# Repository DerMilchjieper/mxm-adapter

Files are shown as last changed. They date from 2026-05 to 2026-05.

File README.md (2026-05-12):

# mxm-adapter

Research and staged hardware concept for reusing the HP ZBook 17 G5 MXM dGPU connector as an external PCIe/OCuLink host link.

## Current design decision

**RevA targets MXM -> OCuLink x4, not MXM -> external PCIe x16.**

Reasoning:

- x4 keeps the first prototype small enough to route and debug.
- OCuLink provides a mechanically realistic cable exit from a laptop chassis.
- Existing OCuLink eGPU docks can supply the PCIe x16 slot and GPU power externally.
- A passive MXM -> external x16 riser has significantly higher signal-integrity and mechanical risk.
- Dual external GPUs are out of scope for RevA and require either host bifurcation that HP has not documented or an active PCIe switch.

## Safety boundary

Do **not** power a desktop PCIe slot or desktop GPU from the notebook MXM rails. The external GPU dock/backplane must have its own ATX/SFX/server PSU. The notebook-side board should only carry PCIe, clock, reset, presence/sideband signals, and protected low-power logic where required.

## Repository layout

```text
.
├── docs/
│   ├── architecture.md
│   ├── assumptions.md
│   ├── dual-gpu-feasibility.md
│   ├── risk-register.md
│   └── validation-plan.md
├── hardware/
│   └── revA-mxm-to-oculink-x4/
│       ├── block-diagram.md
│       ├── netmap.csv
│       ├── schematic-concept.md
│       ├── stackup-and-layout-rules.md
│       └── bom-categories.md
└── README.md
```

## RevA milestone goals

1. Build a passive/mostly-passive MXM Type-B host-side interposer concept.
2. Route PCIe lanes 0-3, REFCLK, PERST#, CLKREQ#, WAKE#, SMBus, PRSNT and selected power-state signals to an OCuLink 4i connector.
3. Keep GPU slot power fully outside the laptop.
4. Validate boot behavior, PCIe enumeration, link width and link speed before attempting x8/x16.

## Non-goals for RevA

- No hotplug support.
- No desktop PCIe slot inside the notebook.
- No x8/x16 cable riser.
- No dual-GPU switch board.
- No attempt to spoof a full HP MXM GPU module unless measurements prove HP EC/BIOS requires it.

## Status

Concept-only. Not fabrication-ready. HP-specific MXM socket behavior must be measured on the actual ZBook 17 G5 before PCB release.

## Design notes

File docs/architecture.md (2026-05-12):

# Architecture

## Recommended architecture: MXM to OCuLink x4

```mermaid
flowchart LR
    CPU[CPU PEG / MXM host interface] --> MXM[MXM 3.0 Type-B edge fingers]
    MXM --> INT[Notebook-side interposer PCB]
    INT --> OC[OCuLink 4i connector]
    OC --> CABLE[External OCuLink cable]
    CABLE --> DOCK[Powered OCuLink eGPU dock]
    DOCK --> GPU[Desktop GPU]
    PSU[ATX/SFX PSU] --> DOCK
    PSU --> GPU
```

## Why x4 OCuLink first

The MXM slot can theoretically expose up to 16 PCIe lanes, but a first prototype should not try to export all lanes. PCIe Gen3 x16 over a custom laptop-exit cable has high signal-integrity risk. A 4-lane OCuLink path is materially easier to validate and uses existing cable/dock ecosystems.

## Alternative: MXM to PCIe x16 external riser

```mermaid
flowchart LR
    MXM[MXM host connector] --> PCB[Interposer / translator PCB]
    PCB --> Riser[High-speed x16 cable/riser]
    Riser --> Slot[External PCIe x16 slot backplane]
    ATX[ATX/SFX PSU] --> Slot
    ATX --> AUX[GPU 6/8-pin or 12VHPWR]
    Slot --> GPU[Desktop GPU]
```

This is theoretically possible but not recommended for RevA. It requires a custom external backplane, high-quality cable assembly, careful power sequencing, and likely redrivers/retimers for robustness.

## Minimal signal groups

### PCIe high speed

- PETp/n[0..3] from host to device
- PERp/n[0..3] from device to host
- REFCLKp/n

### PCIe control / sideband

- PERST#
- CLKREQ#
- WAKE#
- PRSNT#/detect strap equivalents
- SMBus SCL/SDA, isolated or strap-selectable

### Power / reference

- GND stitching and shield grounding
- 3.3 V sense / low-power pull-up domain only if required
- No GPU slot 12 V drawn from MXM

## Power architecture

The external dock/backplane must provide:

- PCIe slot 12 V
- PCIe slot 3.3 V
- AUX 6/8-pin or 12VHPWR GPU power
- over-current protection
- controlled power-on sequencing

The notebook-side board should avoid taking meaningful power from the MXM slot. Any logic rail should be current-limited and fuse-protected.

## Expected user workflow

1. Power off notebook.
2. Connect OCuLink cable.
3. Power external dock/PSU first.
4. Boot notebook.
5. Check PCIe enumeration.
6. Install GPU driver only after stable enumeration.

Hotplug is explicitly not supported for RevA.

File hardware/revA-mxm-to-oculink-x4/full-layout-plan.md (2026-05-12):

# Full RevA layout plan

## Objective

Create a measurement-first MXM Type-B to OCuLink x4 interposer that can be mechanically tested in the HP ZBook 17 G5 and electrically validated against a powered external OCuLink eGPU dock.

## Board concept

- Approximate board class: MXM-B-sized interposer / edge-card surrogate.
- Provisional outline: 94 mm x 32 mm.
- Edge: MXM placeholder at notebook socket side.
- Cable: OCuLink 4i connector near outer edge/cable-exit side.
- Debug: sideband strap matrix and test pads placed away from high-speed corridor.

## Functional blocks

### J1: MXM Type-B host edge

Purpose:

- Mate with the ZBook MXM socket.
- Pick off PCIe lane group 0-3, REFCLK and sideband pins.

Status:

- Placeholder only.
- Requires verified edge-card geometry and HP-specific pin map.

### J2: OCuLink 4i connector

Purpose:

- Export four PCIe lanes to a powered eGPU dock.

Status:

- Placeholder only.
- Replace with exact vendor part footprint before PCB release.

### JP1: sideband strap matrix

Purpose:

- Allow controlled population of PERST#, CLKREQ#, WAKE#, SMBus, PRSNT/detect and possible EC straps.

Default population:

- PERST#: 0R pass-through after verification.
- CLKREQ#: DNI initially; populate if needed.
- WAKE#: DNI initially; populate if needed.
- SMBus: DNI/isolate by default.
- PRSNT/detect: DNI until measured.

### TPx: debug pads

Purpose:

- Probe PERST#, CLKREQ#, WAKE#, SMBus, PRSNT and low-power rails.

Rule:

- No test pads on high-speed PCIe pairs in RevA.

## Routing strategy

1. Lock mechanical outline and connector positions first.
2. Route PCIe lane 0-3 pairs from MXM to OCuLink with the shortest possible path.
3. Route REFCLK as a differential clock pair with continuous reference plane.
4. Add ground stitching around connector transitions.
5. Route sideband signals around the high-speed corridor.
6. Add no high-speed stubs, no unnecessary vias and no high-speed test pads.
7. Add silkscreen warnings and revision labels.

## Suggested layer usage

### 6-layer RevA

| Layer | Use |
|---|---|
| L1 | PCIe/REFCLK primary routing |
| L2 | solid GND reference |
| L3 | sideband / low-speed |
| L4 | low-power islands / sideband |
| L5 | solid GND reference |
| L6 | optional high-speed escape / sideband |

## Differential-pair rules

- PCIe data: target 85 ohm differential.
- REFCLK: target per connector/vendor guidance, commonly 100 ohm differential.
- Final width/gap must come from fabricator stackup calculator, not the placeholder KiCad values.
- Match P/N within each pair.
- Keep inter-pair spacing generous.
- Avoid plane splits.
- Avoid via stubs.

## Placement constraints

### MXM edge

- No tall components near insertion edge.
- No copper/parts in mechanical keepout regions until socket geometry is verified.
- Edge bevel/plating must be manufacturer-reviewed.

### OCuLink connector

- Place near cable exit.
- Add mechanical strain relief to chassis or bracket, not the motherboard.
- Do not let cable insertion force lever against MXM socket.

### Strap/debug area

- Place on accessible top side if the bottom cover is removed.
- Keep away from high-speed channel.
- Label all straps clearly.

## Proposed schematic sheets

1. `J1_MXM_Host`: MXM connector, HP pin verification notes.
2. `PCIE_x4_Path`: lane 0-3 and REFCLK pass-through.
3. `J2_OCuLink`: OCuLink connector and shell/shield strategy.
4. `Sideband_Straps`: PERST, CLKREQ, WAKE, SMBus, PRSNT, optional thermal.
5. `Debug_Protection`: low-power fuse, test pads, ESD footprints DNI.
6. `Mechanical`: mounting/keepout notes and fabrication warnings.

## Fabrication gate

Do not generate Gerbers until all of the following are true:

- MXM pin mapping verified.
- MXM edge geometry verified with coupon.
- OCuLink footprint replaced with real vendor drawing.
- Stackup impedance solved with fabricator.
- DRC passes.
- SI review completed.
- Power isolation reviewed.
- ZBook boot behavior with missing MXM module understood.

## RevA population variants

### Variant A: passive-minimal

- J1, J2 populated.
- PERST# pass-through only after verified.
- All SMBus/detect/thermal straps DNI.

### Variant B: measured-detect

- Same as A.
- PRSNT/detect straps populated to match measured original HP MXM module behavior.

### Variant C: EC-compatible

- Same as B.
- Optional thermal/EC spoof components populated if HP EC requires them.

## Why no x16 in this layout

A full x16 riser from MXM would require a different connector/cable/backplane strategy, likely redrivers/retimers, and far more severe signal-integrity review. It also increases mechanical risk inside the laptop. RevA x4 is the safe proof-of-concept path.

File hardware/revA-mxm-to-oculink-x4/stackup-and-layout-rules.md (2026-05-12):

# Stackup and layout rules

## Recommended PCB stackup

Minimum: 6 layers. Preferred: 8 layers if board area and escape routing are tight.

### 6-layer candidate

1. L1: high-speed signals / short escapes
2. L2: solid GND reference
3. L3: low-speed signals / sideband
4. L4: power islands / sideband
5. L5: solid GND reference
6. L6: high-speed signals / connector escape

### 8-layer candidate

1. L1: high-speed signals
2. L2: solid GND
3. L3: high-speed signals if needed
4. L4: solid GND
5. L5: low-speed / power islands
6. L6: solid GND
7. L7: sideband
8. L8: mechanical/debug/low-speed

## Impedance targets

- PCIe data pairs: 85 ohm differential target.
- REFCLK: follow connector/cable vendor guidance; commonly routed as 100 ohm differential clock.
- Use the PCB fabricator's field solver for the chosen stackup.

## Routing constraints

- Keep MXM-to-OCuLink high-speed path as short as mechanically possible.
- Avoid layer changes for PCIe pairs where possible.
- If vias are required, use symmetric via transitions and minimize stubs.
- Maintain continuous GND reference under every high-speed pair.
- Do not cross plane splits.
- Avoid test pads, stubs and probing structures on high-speed pairs.
- Do not place ESD devices on high-speed nets unless their capacitance and placement are validated.
- Keep pair-to-pair spacing wide enough to control crosstalk.
- Length match P/N within each pair according to fabricator/SI guidance.
- Inter-lane matching is less critical than intra-pair matching for PCIe but should still be sane.

## OCuLink connector area

- Follow the chosen connector vendor's footprint exactly.
- Provide shell/shield grounding pads and stitching vias.
- Add mechanical reinforcement if the cable exits the chassis with stress.
- Define whether shield bonds directly to digital GND or via RC/ESD structure after mechanical/chassis review.

## MXM edge area

- Edge fingers require correct thickness, bevel and plating.
- Confirm insertion depth and keeper/retention behavior in the ZBook MXM socket.
- Verify no components collide with heatsink, frame, keyboard deck, fan duct or bottom cover.

## Redriver/retimer decision

RevA starts passive. Add redriver/retimer only after:

1. Passive x4 fails to train reliably at Gen3.
2. Gen2 works but Gen3 is unstable.
3. Cable length cannot be reduced.
4. Eye/SI evidence suggests insertion loss is the dominant issue.

A retimer spin is a different architecture and should become RevB.

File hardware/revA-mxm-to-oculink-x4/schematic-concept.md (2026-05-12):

# RevA schematic concept

## Sheet 1: MXM host connector

Components:

- J1: MXM 3.0 Type-B edge-finger symbol/footprint placeholder.
- TP group: all sideband pins broken out.
- DNI strap resistors for presence/detect and EC-facing signals.

Notes:

- Use a mechanically accurate MXM Type-B outline before PCB work.
- Pin numbering must be verified against the chosen connector/edge-footprint convention.
- Do not trust generic internet pinouts for HP-specific behavior.

## Sheet 2: PCIe x4 high-speed path

Nets:

- PET/PER lanes 0-3.
- REFCLK pair.
- Optional AC-coupling capacitor footprints only where required by the interface convention. Do not blindly duplicate endpoint-side coupling if the dock/card already provides it.

Components:

- J2: OCuLink 4i connector.
- Optional low-cap ESD arrays, DNI by default until SI budget is reviewed.
- Optional common-mode choke footprints are not recommended for first spin unless justified by the connector/cable vendor.

Routing:

- No vias if possible between MXM breakout and OCuLink connector.
- If vias are unavoidable, use backdrill-capable stackup or keep stubs minimal.
- Length-match within each differential pair first; inter-lane matching is secondary for PCIe.

## Sheet 3: sideband and strap matrix

Signals:

- PERST#
- CLKREQ#
- WAKE#
- PRSNT#/detect
- SMBus SCL/SDA
- optional THERM#/ALERT#/FAN_TACH-like signals if HP exposes them on MXM

Implementation:

- 0-ohm jumpers for direct pass-through vs isolation.
- Pull-up/down resistor footprints for detect straps.
- Series resistor placeholders on sideband lines.
- Test pads before and after jumpers.

Default population:

- PERST#: pass-through populated.
- PRSNT#/detect: unpopulated until measured.
- SMBus: isolated by default.
- CLKREQ#/WAKE#: testable; populate as required.
- Thermal spoof: DNI.

## Sheet 4: protected low-power domain

Goal:

Only provide local pull-ups or indicators if required. Do not create a significant load on the MXM power rails.

Possible components:

- Resettable fuse or eFuse for any 3.3 V use.
- TVS/ESD for exposed sideband connector pins.
- Power-good LED, DNI by default.

## Sheet 5: mechanical and debug

- Mounting holes matching safe internal locations only after ZBook mechanical survey.
- Strain relief for OCuLink cable.
- Ground test pads.
- Optional board ID EEPROM footprint, DNI.

## Explicitly excluded from RevA

- PCIe switch.
- Redriver/retimer.
- x8/x16 export.
- ATX power controller.
- External PCIe slot.
- Any attempt to source GPU slot power from the notebook.

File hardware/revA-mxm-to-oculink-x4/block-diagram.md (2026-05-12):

# RevA block diagram: MXM to OCuLink x4

```mermaid
flowchart TB
    subgraph Notebook[HP ZBook 17 G5]
        CPU[CPU PEG root port]
        EC[Embedded controller / BIOS]
        MXM[MXM Type-B host connector]
        CPU --> MXM
        EC -. detect / reset / thermal / SMBus .- MXM
    end

    subgraph Interposer[RevA MXM-to-OCuLink interposer]
        EDGE[MXM edge connector fingers]
        STRAPS[strap matrix + DNI options]
        TP[test pads]
        ESD[low-cap ESD footprints, DNI unless validated]
        OCULINK[OCuLink 4i SFF-8612/SFF-8611]
        EDGE --> STRAPS
        EDGE --> TP
        EDGE --> ESD
        ESD --> OCULINK
    end

    subgraph External[eGPU side]
        CABLE[OCuLink cable]
        DOCK[Powered OCuLink eGPU dock]
        GPU[Desktop GPU]
        PSU[ATX/SFX/server PSU]
        PSU --> DOCK
        PSU --> GPU
        DOCK --> GPU
    end

    MXM --> EDGE
    OCULINK --> CABLE
    CABLE --> DOCK
```

## Board partitions

1. **MXM finger area**: mates with the notebook MXM socket and keeps all high-speed breakout lengths short.
2. **High-speed escape region**: routes PCIe x4 and REFCLK with uninterrupted reference planes.
3. **Sideband strap/test region**: exposes PERST#, CLKREQ#, WAKE#, PRSNT#/detect, SMBus, optional thermal spoof.
4. **Cable connector region**: OCuLink 4i with robust retention and mechanical strain relief.

## Intended mechanical shape

The board should mimic the MXM module insertion edge and occupy the minimum internal volume required to exit an OCuLink cable path. A flex or short cabled OCuLink pigtail may be mechanically easier than a rigid connector placed directly at the MXM area, but this must not violate PCIe Gen3 signal-integrity limits.

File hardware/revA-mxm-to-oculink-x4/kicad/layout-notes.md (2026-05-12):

# KiCad layout skeleton

This directory contains a **real KiCad project skeleton** for the RevA MXM-to-OCuLink-x4 concept.

## Files

- `revA-mxm-to-oculink-x4.kicad_pro` — KiCad project settings and placeholder net classes.
- `revA-mxm-to-oculink-x4.kicad_sch` — schematic stub pointing to the documentation-first design.
- `revA-mxm-to-oculink-x4.kicad_pcb` — mechanical/electrical PCB skeleton.

## What is in the PCB file

- 94 mm × 32 mm provisional board outline.
- MXM Type-B edge-finger **placeholder** with 314 pads.
- OCuLink 4i connector **placeholder**.
- Sideband strap-matrix placeholder.
- Preliminary PCIe x4 / REFCLK / sideband net names.
- Drawing-layer high-speed corridor and “do not fabricate” markings.

## What is intentionally not solved yet

- Exact HP ZBook 17 G5 MXM pin mapping.
- Verified MXM edge-card geometry, bevel, plating and insertion depth.
- Verified OCuLink connector footprint from a real vendor part.
- Verified controlled-impedance stackup from a board fabricator.
- Exact lane mapping, polarity, AC-coupling locations and sideband strap values.
- Mechanical retention and cable strain-relief.

## Why the layout is not fabrication-ready

This file is meant to be opened in KiCad to start mechanical review and layout planning. It is **not** a Gerber-ready adapter. The placeholder pad assignments include `_TBD` in net names on purpose. Do not remove that until the ZBook MXM slot has been measured and reviewed.

## Next layout actions

1. Replace the MXM placeholder with a verified edge-card geometry.
2. Replace the OCuLink placeholder with the exact connector vendor footprint.
3. Update `netmap.csv` with measured HP-specific MXM pin mapping.
4. Re-annotate nets in schematic and PCB.
5. Define final 6- or 8-layer stackup with the PCB manufacturer.
6. Run DRC, SI review and mechanical clearance review.
7. Build a non-electrical mechanical coupon before any powered PCB.

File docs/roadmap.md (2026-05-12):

# Roadmap

## Stage 0: baseline OCuLink eGPU

Goal: prove the laptop can use an external GPU through an easier path.

- Use M.2 NVMe -> OCuLink adapter.
- Use powered OCuLink dock.
- Connect monitor directly to GPU.
- Record link speed, link width, boot behavior and driver stability.

Exit criteria:

- Stable boot and gaming/compute workload on M.2 OCuLink.

## Stage 1: MXM platform characterization

Goal: learn how HP handles the MXM slot.

- Document installed MXM module.
- Test boot with MXM module removed if safe.
- Record BIOS behavior.
- Measure sideband timing.
- Identify detect/thermal dependencies.

Exit criteria:

- Known boot behavior with and without MXM module.
- Candidate sideband requirements identified.

## Stage 2: mechanical coupon

Goal: validate board fit without electrical risk.

- Fabricate edge-card outline coupon.
- Validate thickness, bevel, insertion depth and retention.
- Validate OCuLink cable path.
- Validate no chassis/heatsink collision.

Exit criteria:

- Physical fit confirmed.
- Cable strain-relief concept confirmed.

## Stage 3: RevA passive x4 board

Goal: enumerate one external GPU over MXM-derived PCIe x4.

- Route lanes 0-3 to OCuLink.
- Add sideband straps/test pads.
- Keep SMBus isolated by default.
- Use external powered OCuLink dock.

Exit criteria:

- External GPU enumerates.
- Stable Gen2 x4 minimum; Gen3 x4 target.

## Stage 4: RevB robustness spin

Only if RevA proves the platform concept.

Potential additions:

- Redriver/retimer.
- Improved mechanical strain relief.
- Better sideband conditioning.
- Optional x8 if mechanical/SI budget supports it.

## Stage 5: dual-GPU experiment

Only after M.2 OCuLink and MXM OCuLink are independently stable.

- Boot with both external paths populated.
- Record PCIe topology.
- Test AMD gaming GPU + Nvidia compute GPU split.
- Avoid multi-GPU gaming as a target.

## Stage 6: x16 riser exploration

This remains a research branch, not the default product path.

Requirements before attempting:

- Proven MXM enumeration.
- High-speed layout review.
- External PCIe slot power/backplane design.
- Mechanical enclosure concept.
- Acceptance that redriver/retimer may be required.

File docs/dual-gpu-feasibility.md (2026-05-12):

# Dual external GPU feasibility

## Question

Can the ZBook 17 G5 theoretically run two external desktop GPUs, for example:

1. GPU A through M.2 NVMe -> OCuLink x4.
2. GPU B through MXM -> OCuLink x4 or MXM -> PCIe riser.

## Short answer

**Theoretically yes, practically uncertain and not a RevA goal.**

The platform may expose independent PCIe root ports for the CPU PEG/MXM path and PCH/M.2 NVMe path. If firmware enumerates both, Windows/Linux can generally handle multiple GPUs. The hard blockers are firmware behavior, physical integration, power sequencing and driver stability.

## Likely topology

```mermaid
flowchart TB
    CPU[i7-8850H CPU]
    PCH[Mobile PCH]
    MXM[MXM dGPU slot]
    M2[M.2 NVMe slot]
    OC1[OCuLink dock A]
    OC2[OCuLink dock B]
    GPU1[External GPU 1]
    GPU2[External GPU 2]

    CPU -->|PEG lanes, originally dGPU| MXM
    CPU -->|DMI link| PCH
    PCH -->|PCIe x4 NVMe root port| M2
    MXM --> OC1 --> GPU1
    M2 --> OC2 --> GPU2
```

## Bandwidth considerations

- MXM-derived GPU path could be CPU PEG and avoid PCH/DMI bottleneck if firmware exposes it cleanly.
- M.2 NVMe-derived OCuLink path likely traverses the PCH and DMI link.
- Two GPUs doing heavy peer-to-peer or simultaneous host transfers can contend for CPU, memory, DMI and thermal/power management.
- For gaming on one GPU and compute on the other, bandwidth contention may be acceptable.
- For two gaming GPUs, modern multi-GPU rendering is mostly unsupported and not worthwhile.

## Firmware constraints

Potential blockers:

- BIOS may require an HP-recognized MXM module.
- BIOS may not initialize external GPU-like endpoint on MXM without video BIOS expectations.
- BIOS may not support bifurcation of MXM PEG lanes into multiple devices.
- M.2 port may not support hotplug and must see device at boot.
- Boot graphics selection may conflict with external-only paths.

## Driver constraints

- AMD + Nvidia mixed drivers are usually possible but can be messy.
- Nvidia CMP cards may be compute-only/no-display and better suited to CUDA workloads.
- AMD eGPU for display plus Nvidia CMP for compute is an attractive theoretical split.
- Anti-cheat and VM passthrough scenarios can add unrelated failure modes.

## Power and mechanical constraints

Two external GPUs require:

- two powered docks or a custom dual-slot external backplane;
- independent PSU capacity;
- safe power sequencing;
- mechanically safe cable exits;
- no load on notebook internal GPU power rails.

## Practical recommendation

1. First validate M.2 -> OCuLink with one GPU.
2. Then validate MXM -> OCuLink x4 as RevA.
3. Only after both are independently stable, attempt simultaneous enumeration.
4. Do not design a dual-GPU board until single-link MXM behavior is proven.

## Best theoretical use case

- External AMD/Nvidia gaming GPU on one link, monitor attached directly.
- One or more Nvidia CMP/compute GPUs in a separate desktop/server or on another dock for CUDA/ComfyUI/Ollama experiments.

## Worst use case

- Two external gaming GPUs for combined rendering. This is not a sensible target because modern games rarely support explicit multi-GPU effectively.

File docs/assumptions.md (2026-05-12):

# Design assumptions

## Target platform

- Host notebook: HP ZBook 17 G5 mobile workstation.
- CPU family: Intel 8th Gen H-series, user-reported i7-8850H.
- Internal dGPU slot: MXM 3.0 Type B class connector/module form factor.
- Existing external path: M.2 NVMe to OCuLink is treated as the lower-risk baseline.

## Known unknowns

The following must be verified by measurement or official board-level documentation before any PCB is fabricated:

1. Exact HP MXM pin usage and any vendor-specific straps.
2. Whether the ZBook firmware enumerates a non-GPU PCIe endpoint on the MXM link.
3. Required PRSNT#/module-detect behavior.
4. Required thermal/fan/EC signals when no HP MXM module is present.
5. Whether PEG lanes are x16-only or can train down to x8/x4 without a valid MXM vBIOS device.
6. Whether the system boots without an installed MXM graphics module.
7. Whether internal display routing depends on the removed MXM dGPU.

## Conservative electrical assumptions

- Use PCIe Gen3 as the design target.
- Assume 85 ohm differential impedance for PCIe data pairs.
- Assume 100 ohm differential impedance for REFCLK unless connector/cable vendor specifies otherwise.
- Treat all high-speed lanes as polarity-sensitive until verified.
- Avoid passive cable lengths beyond validated OCuLink cable assemblies.
- Do not route desktop slot power through the notebook-side PCB.

## Firmware assumptions

The HP BIOS/EC may require MXM presence and thermal-management signals even if the external GPU is electrically valid. RevA must therefore expose test pads and strap options for:

- PRSNT#/module detect
- SMBus pull-ups/isolation
- WAKE#
- CLKREQ#
- PERST# observation/injection
- optional thermal sensor spoofing footprint, DNI by default

## Design philosophy

RevA is a measurement-first board. It should make the platform observable before it tries to maximize performance.

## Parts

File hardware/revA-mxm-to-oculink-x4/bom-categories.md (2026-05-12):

# BOM categories

## Connector and mechanical

- MXM Type-B edge-card PCB implementation or mating connector strategy, depending on final mechanical approach.
- OCuLink 4i connector, SFF-8612/SFF-8611 family depending on cable/dock.
- Cable-retention bracket or strain-relief hardware.
- Kapton/insulation films for internal chassis clearance.
- Mounting hardware only where it does not stress the ZBook motherboard.

## Passive high-speed path

- AC-coupling capacitor footprints if required by the chosen topology.
- Optional 0-ohm lane-swap/polarity rework footprints only if they do not create stubs.
- Low-cap ESD arrays, DNI by default.

## Sideband and straps

- 0-ohm jumpers for PERST#, CLKREQ#, WAKE#, SMBus, detect lines.
- Pull-up/pull-down resistor arrays for presence and EC straps.
- Series resistors for sideband damping/isolation.
- Test pads for every sideband net.

## Protection and low-power

- Resettable fuse/eFuse for any local 3.3 V usage.
- TVS for low-speed external-facing nets if exposed.
- Optional LED indicators, DNI by default.

## Debug

- Ground test loops.
- PERST#/CLKREQ#/WAKE# test pads.
- SMBus test pads.
- Optional tiny logic-analyzer header if it fits mechanically.

## External dock requirements

The external dock is treated as a separate assembly and must provide:

- PCIe slot connector.
- ATX/SFX/server PSU input.
- PCIe slot 12 V and 3.3 V.
- AUX GPU power cabling.
- Power switch and power-good behavior.
- Physical GPU support.

RevA should be compatible with an existing powered OCuLink eGPU dock instead of implementing this from scratch.

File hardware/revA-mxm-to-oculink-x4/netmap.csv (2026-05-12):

net_name | source_group | destination_group | required_for_reva | notes
PCIE_TX0_P | MXM PET lane 0 + | OCuLink host TX lane 0 + | yes | Verify MXM lane orientation against HP board and OCuLink pinout
PCIE_TX0_N | MXM PET lane 0 - | OCuLink host TX lane 0 - | yes | Pair length match tightly
PCIE_RX0_P | MXM PER lane 0 + | OCuLink host RX lane 0 + | yes | Verify polarity and lane reversal support
PCIE_RX0_N | MXM PER lane 0 - | OCuLink host RX lane 0 - | yes | Pair length match tightly
PCIE_TX1_P | MXM PET lane 1 + | OCuLink host TX lane 1 + | yes | Verify MXM lane orientation against HP board and OCuLink pinout
PCIE_TX1_N | MXM PET lane 1 - | OCuLink host TX lane 1 - | yes | Pair length match tightly
PCIE_RX1_P | MXM PER lane 1 + | OCuLink host RX lane 1 + | yes | Verify polarity and lane reversal support
PCIE_RX1_N | MXM PER lane 1 - | OCuLink host RX lane 1 - | yes | Pair length match tightly
PCIE_TX2_P | MXM PET lane 2 + | OCuLink host TX lane 2 + | yes | Verify MXM lane orientation against HP board and OCuLink pinout
PCIE_TX2_N | MXM PET lane 2 - | OCuLink host TX lane 2 - | yes | Pair length match tightly
PCIE_RX2_P | MXM PER lane 2 + | OCuLink host RX lane 2 + | yes | Verify polarity and lane reversal support
PCIE_RX2_N | MXM PER lane 2 - | OCuLink host RX lane 2 - | yes | Pair length match tightly
PCIE_TX3_P | MXM PET lane 3 + | OCuLink host TX lane 3 + | yes | Verify MXM lane orientation against HP board and OCuLink pinout
PCIE_TX3_N | MXM PET lane 3 - | OCuLink host TX lane 3 - | yes | Pair length match tightly
PCIE_RX3_P | MXM PER lane 3 + | OCuLink host RX lane 3 + | yes | Verify polarity and lane reversal support
PCIE_RX3_N | MXM PER lane 3 - | OCuLink host RX lane 3 - | yes | Pair length match tightly
REFCLK_P | MXM PCIe reference clock + | OCuLink REFCLK + | yes | Route as clock differential pair; consider AC-coupling only if spec requires
REFCLK_N | MXM PCIe reference clock - | OCuLink REFCLK - | yes | Route as clock differential pair
PERST_N | MXM reset sideband | OCuLink PERST# | yes | Expose test pad and optional buffer/level option
CLKREQ_N | MXM clock request sideband | OCuLink CLKREQ# | maybe | Strap/test; required if platform uses L1 substates or dynamic clocking
WAKE_N | MXM wake sideband | OCuLink WAKE# | maybe | Expose test pad; may be optional for always-on external dock
SMB_CLK | MXM SMBus clock | OCuLink/dock SMBus or isolated pad | maybe | Default DNI isolation; avoid bus conflict until measured
SMB_DATA | MXM SMBus data | OCuLink/dock SMBus or isolated pad | maybe | Default DNI isolation; avoid bus conflict until measured
PRSNT_DETECT | MXM module present strap | strap matrix | yes | Populate only after HP detect behavior is measured
THERM_ALERT | MXM thermal/alert if present | strap/test/optional spoof | unknown | Do not assume; verify HP EC requirements
3V3_AUX_SENSE | MXM low power rail/test | logic pull-ups only | no | Current-limit if used; do not power external dock
GND | MXM ground | OCuLink shield and signal reference | yes | Use dense stitching | connector shell strategy to be reviewed
SHIELD | OCuLink connector shell | chassis/cable shield | yes | Define chassis vs digital ground bond after mechanical review
RESERVED_X8_LANES | MXM lanes 4-7 | not connected in RevA | no | Escape/test pads optional only
RESERVED_X16_LANES | MXM lanes 8-15 | not connected in RevA | no | Do not route on RevA unless board area allows measurement pads

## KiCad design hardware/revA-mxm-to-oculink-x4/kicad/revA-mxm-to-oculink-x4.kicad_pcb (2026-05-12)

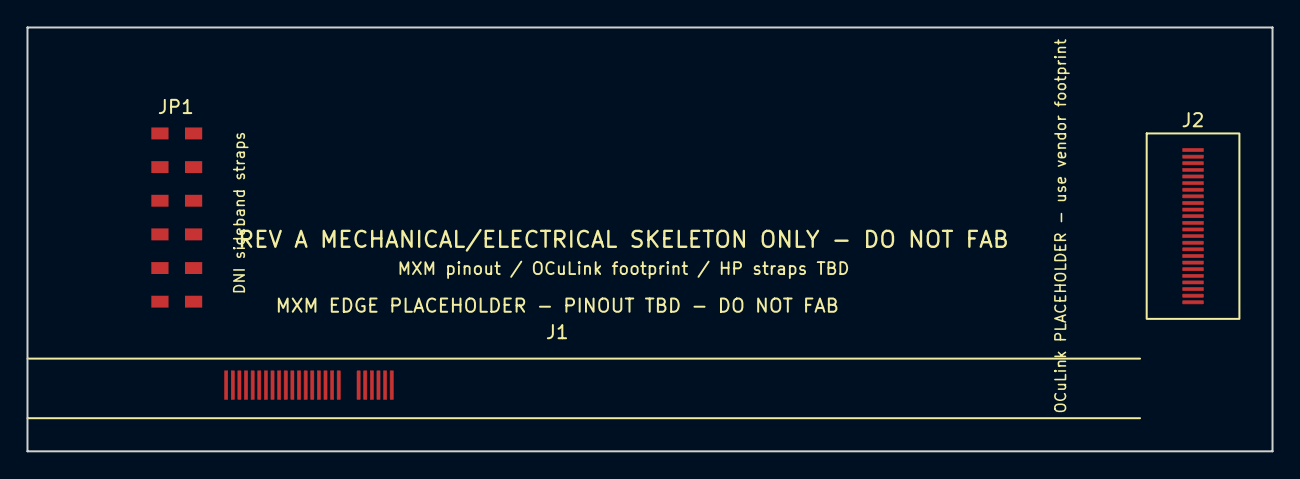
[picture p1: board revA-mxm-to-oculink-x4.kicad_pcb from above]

Board: 6 copper layers, 94.0 x 32.0 mm, 3 parts (0 on the bottom side), 24 nets, no tracks yet.

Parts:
J1: MXM3_TYPE_B_EDGE_PLACEHOLDER; MXM3_TYPE_B_EDGE_PLACEHOLDER_DO_NOT_FAB
J2: OCuLink_4i_PLACEHOLDER; OCULINK_4I_PLACEHOLDER_DO_NOT_FAB
JP1: DNI_STRAPS; SIDEBAND_STRAP_MATRIX_0603_PLACEHOLDER

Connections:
CLKREQ_N_TBD: J1.A41, J2.CLKREQ, JP1.CLKREQ_N_TBD_A
PCIE_RX0_N_TBD: J1.A23, J2.RX0N
PCIE_RX0_P_TBD: J1.A22, J2.RX0P
PCIE_RX1_N_TBD: J1.A27, J2.RX1N
PCIE_RX1_P_TBD: J1.A26, J2.RX1P
PCIE_RX2_N_TBD: J1.A31, J2.RX2N
PCIE_RX2_P_TBD: J1.A30, J2.RX2P
PCIE_RX3_N_TBD: J1.A35, J2.RX3N
PCIE_RX3_P_TBD: J1.A34, J2.RX3P
PCIE_TX0_N_TBD: J1.A21, J2.TX0N
PCIE_TX0_P_TBD: J1.A20, J2.TX0P
PCIE_TX1_N_TBD: J1.A25, J2.TX1N
PCIE_TX1_P_TBD: J1.A24, J2.TX1P
PCIE_TX2_N_TBD: J1.A29, J2.TX2N
PCIE_TX2_P_TBD: J1.A28, J2.TX2P
PCIE_TX3_N_TBD: J1.A33, J2.TX3N
PCIE_TX3_P_TBD: J1.A32, J2.TX3P
PERST_N_TBD: J1.A40, J2.PERST, JP1.PERST_N_TBD_A
PRSNT_DETECT_TBD: J1.A45, J2.PRSNT, JP1.PRSNT_DETECT_TBD_A
REFCLK_N_TBD: J1.A37, J2.REFN
REFCLK_P_TBD: J1.A36, J2.REFP
SMB_CLK_TBD: J1.A43, J2.SCL, JP1.SMB_CLK_TBD_A
SMB_DATA_TBD: J1.A44, J2.SDA, JP1.SMB_DATA_TBD_A
WAKE_N_TBD: J1.A42, J2.WAKE, JP1.WAKE_N_TBD_A

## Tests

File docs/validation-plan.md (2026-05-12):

# Validation plan

## Phase 0: non-invasive platform survey

1. Photograph MXM bay, heatsink, retention hardware and cable exit candidates.
2. Record current internal GPU model, BIOS version and graphics mode settings.
3. Boot with original MXM GPU and collect:
   - Windows Device Manager screenshot
   - GPU-Z bus interface
   - Linux `lspci -vv` if available
   - BIOS graphics settings
4. Identify whether the notebook can boot with MXM module removed.

## Phase 1: electrical measurement before PCB

With power disconnected:

- Map grounds on MXM area.
- Identify low-impedance power pins carefully.
- Verify likely presence/detect pins against known MXM references.

With original MXM GPU installed and system powered:

- Observe PERST# timing.
- Observe REFCLK presence if suitable equipment is available.
- Observe CLKREQ#/WAKE# state.
- Observe SMBus activity only with high-impedance probing.

Do not short or strap unknown pins.

## Phase 2: dummy interposer / continuity article

Fabricate a no-connect mechanical coupon first if possible:

- Validate edge-card thickness and bevel.
- Validate insertion depth.
- Validate clearance under bottom cover/heatsink region.
- Validate OCuLink cable exit without stressing motherboard.

## Phase 3: RevA passive x4 bring-up

1. Install RevA with no external GPU connected.
2. Verify notebook power-on behavior.
3. Connect powered OCuLink dock with low-risk test GPU.
4. Boot with external dock powered first.
5. Check enumeration:
   - Linux: `lspci -nn`, `lspci -vv`
   - Windows: Device Manager, GPU-Z
6. Check negotiated link:
   - width: x1/x2/x4
   - speed: Gen1/Gen2/Gen3
7. Install driver only after stable enumeration.

## Phase 4: stability testing

- Cold boot repeatability: 20 cycles.
- Warm reboot repeatability: 20 cycles.
- GPU idle stability: 1 hour.
- PCIe link retrain monitoring.
- Light 3D workload.
- Heavy 3D workload.
- Sleep/resume is not required for RevA and should be disabled initially.

## Phase 5: failure classification

| Symptom | Likely class | Next action |
|---|---|---|
| Notebook does not power on | detect/power/EC conflict | remove immediately, inspect straps |
| Boots but no PCIe device | reset/clock/presence/lane issue | inspect PERST#/REFCLK/PRSNT |
| Device appears at Gen1 only | SI/cable/insertion loss | shorten path, consider RevB redriver |
| Device appears x1/x2 only | lane mapping/lane training issue | validate lane order and polarity |
| Driver loads then crashes | power/dock/GPU/driver issue | test known-good GPU/dock |
| Random disconnects under load | SI or dock power | log AER errors, reduce Gen speed |

## Success criteria for RevA

- System boots consistently.
- External GPU enumerates.
- Link trains at PCIe Gen3 x4 or stable Gen2 x4.
- No thermal or EC faults.
- No unsafe heating on notebook-side board.
- No dependence on hotplug.

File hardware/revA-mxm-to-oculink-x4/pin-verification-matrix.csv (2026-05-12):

item | signal_group | candidate_net | status | verification_method | pass_condition | notes
1 | PCIe lane0 | PCIE_TX0_P/N_TBD | unverified | continuity + compare against original MXM module | host TX pair orientation known | Do not route to final until verified
2 | PCIe lane0 | PCIE_RX0_P/N_TBD | unverified | continuity + compare against original MXM module | host RX pair orientation known | Do not route to final until verified
3 | PCIe lane1 | PCIE_TX1_P/N_TBD | unverified | continuity + compare against original MXM module | host TX pair orientation known | Do not route to final until verified
4 | PCIe lane1 | PCIE_RX1_P/N_TBD | unverified | continuity + compare against original MXM module | host RX pair orientation known | Do not route to final until verified
5 | PCIe lane2 | PCIE_TX2_P/N_TBD | unverified | continuity + compare against original MXM module | host TX pair orientation known | Do not route to final until verified
6 | PCIe lane2 | PCIE_RX2_P/N_TBD | unverified | continuity + compare against original MXM module | host RX pair orientation known | Do not route to final until verified
7 | PCIe lane3 | PCIE_TX3_P/N_TBD | unverified | continuity + compare against original MXM module | host TX pair orientation known | Do not route to final until verified
8 | PCIe lane3 | PCIE_RX3_P/N_TBD | unverified | continuity + compare against original MXM module | host RX pair orientation known | Do not route to final until verified
9 | Clock | REFCLK_P/N_TBD | unverified | oscilloscope differential probe if available or indirect link training | 100MHz present when endpoint expected | Do not load clock net with large probe capacitance
10 | Reset | PERST_N_TBD | unverified | logic analyzer / scope | asserted during boot then released | Expose test pad
11 | Clock request | CLKREQ_N_TBD | unverified | logic analyzer / scope | state understood with original MXM card | Optional in RevA
12 | Wake | WAKE_N_TBD | unverified | logic analyzer / scope | state understood with original MXM card | Optional in RevA
13 | SMBus | SMB_CLK_TBD | unverified | high impedance probing | bus not shorted and voltage level known | Default isolated
14 | SMBus | SMB_DATA_TBD | unverified | high impedance probing | bus not shorted and voltage level known | Default isolated
15 | Presence | PRSNT_DETECT_TBD | unverified | resistance/strap measurement with original module | required strap known | Populate only after measured
16 | Thermal/EC | THERM_ALERT_TBD | unknown | service docs + measurements | no EC boot fault | Optional spoof footprint only after identified
17 | Power | 3V3_AUX_TBD | unverified | DMM current-limited measurement | voltage and max safe current known | Do not use for external dock power
18 | Ground | GND | partially verified | DMM continuity to chassis/board ground | low impedance ground reference | Use dense stitching
19 | Mechanical | MXM_EDGE_GEOMETRY_TBD | unverified | mechanical coupon | inserts without force and no collision | First fabrication should be coupon
20 | Mechanical | OCULINK_FOOTPRINT_TBD | unverified | vendor drawing + sample connector | connector solders and cable latches correctly | Replace placeholder footprint

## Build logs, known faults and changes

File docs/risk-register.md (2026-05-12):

# Risk register

| ID | Risk | Severity | Likelihood | Mitigation |
|---|---|---:|---:|---|
| R1 | Wrong MXM pin mapping damages motherboard | Critical | Medium | Do not fabricate before pinout verification; use continuity/mechanical coupon first |
| R2 | HP BIOS/EC refuses boot without HP MXM GPU | High | Medium | Test boot without MXM; expose detect/thermal straps; keep original module recoverable |
| R3 | PCIe Gen3 signal integrity failure | High | Medium | Start x4 passive; shortest path; controlled impedance; fall back to Gen2; RevB redriver if needed |
| R4 | OCuLink cable mechanical stress damages MXM socket | High | Medium | Add strain relief; avoid rigid lever arm; validate cable exit with dummy board |
| R5 | External GPU power backfeeds notebook | Critical | Low/Medium | Do not connect external slot power to MXM rails; isolate low-power sideband where needed |
| R6 | SMBus conflict between dock/GPU and HP EC | Medium | Medium | SMBus isolated by default; populate jumpers only after measurement |
| R7 | Thermal/fan EC fault due to missing MXM module | Medium | Medium | Identify thermal pins; optional spoof footprint; BIOS testing with original module removed |
| R8 | Hotplug event causes crash or damage | High | Medium | RevA forbids hotplug; require cold connection and dock powered before boot |
| R9 | Internal display no longer works as expected | Medium | Medium | Use external monitor on eGPU; keep iGPU/dGPU BIOS settings documented |
| R10 | Dual GPU setup unstable | Medium | High | Not RevA; validate each path independently before simultaneous testing |
| R11 | Fabricator cannot meet edge-card/mechanical tolerances | High | Medium | Use vendor DFM review; create mechanical coupon first |
| R12 | Legal/licensing issue with proprietary MXM pinout documents | Medium | Low | Do not commit confidential docs; document derived measurements and public references only |

## Go / no-go gates

### Gate A: before schematic capture

- HP-specific MXM behavior has at least a measurement plan.
- Original MXM module can be reinstalled safely.
- Mechanical cable path is plausible.

### Gate B: before PCB fabrication

- Edge-card geometry verified.
- Pin mapping reviewed.
- Power isolation reviewed.
- No unknown power pin is routed to external connector.
- DFM check passed.

### Gate C: before powered test

- Continuity checked.
- Shorts to power and ground checked.
- External dock tested independently.
- Current-limited first power-on plan documented.

### Gate D: before expensive GPU test

- Use sacrificial/low-value GPU first.
- Confirm enumeration and link training.
- Confirm no abnormal heating.

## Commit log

2026-05-12 Add preliminary RevA netmap
    [netmap.csv]
2026-05-12 Add RevA schematic concept
2026-05-12 Add BOM categories
2026-05-12 Add staged roadmap
2026-05-12 Add KiCad layout notes
2026-05-12 Add KiCad project skeleton
2026-05-12 Add KiCad schematic stub
    [revA-mxm-to-oculink-x4.kicad_sch]
2026-05-12 Add KiCad PCB layout skeleton
    [revA-mxm-to-oculink-x4.kicad_pcb]
2026-05-12 Add KiCad symbol library for RevA
2026-05-12 Add HP MXM pin verification matrix
    [pin-verification-matrix.csv]
2026-05-12 Expand KiCad schematic documentation stub
    [revA-mxm-to-oculink-x4.kicad_sch]
